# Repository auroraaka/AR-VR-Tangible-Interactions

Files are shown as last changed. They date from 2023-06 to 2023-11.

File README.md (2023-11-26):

# AR-VR-Tangible-Interactions
Created infrared (IR) camera and light attachments for Microsoft Hololens 1 and Oculus Quest 2. SolidWorks and STEP files are provided for CAD models (Hardware>IR_Camera_Apparatus>Microsoft_Hololens_1/Oculus_Quest_2). KiCad files are provided for the PCB and schematic of a compact IR light circuit (Hardware>IR_Camera_Apparatus>IR_Light). 

Programmed computer vision algorithms in Python to detect AruCo codes inside a custom-designed Ping Pong Paddle and Lightsaber. STL files are provided for the empty models and AruCo codes (Hardware>Ping_Pong_Paddle/Lightsaber). 

Mapped object movements to play:
- [Konterball](https://konterball.com/) in a web XR environment using 2D-to-3D conversion system assisted by PyAutoGUI (Software>Konterball).
- [Fruit Ninja](https://github.com/zigurous/unity-fruit-ninja-tutorial) in a wired PC-VR environment using C# scripts in Unity (Sofware>Fruit_Ninja). 

# Quick Links
__**ACM UIST Citation:**__  
Mustafa Doga Dogan, Raul Garcia-Martin, Patrick William Haertel, Jamison John O'Keefe, Ahmad Taka, Akarsh Aurora, Raul Sanchez-Reillo, and Stefanie Mueller. 2023. BrightMarker: 3D Printed Fluorescent Markers for Object Tracking. In Proceedings of the 36th Annual ACM Symposium on User Interface Software and Technology (UIST '23). Association for Computing Machinery, New York, NY, USA, Article 55, 1–13. https://doi.org/10.1145/3586183.3606758

__**Demo Video:**__    
Unlocking the Secret of BrightMarker: 3D Printed Fluorescent Markers for Object Tracking (https://www.youtube.com/watch?v=M5YNR6cVIiM)

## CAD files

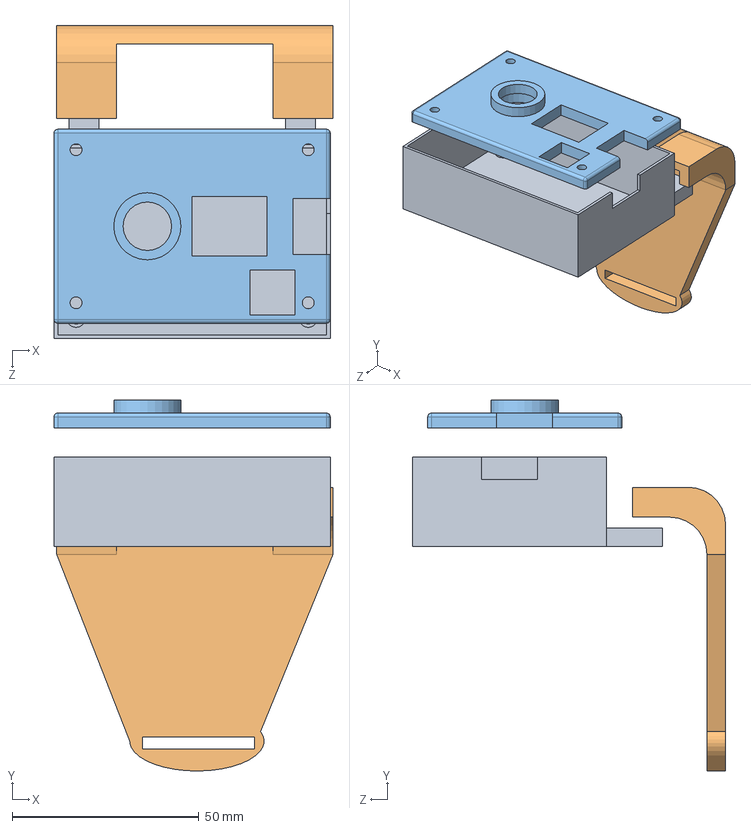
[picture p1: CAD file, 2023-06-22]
Hardware/IR_Camera_Apparatus/Oculus_Quest_2/SolidWorks/Oculus Quest 2 Assembly.SLDASM
74.7 x 99.4 x 83.9 mm
Oculus Quest 2 Bottom
Oculus Quest 2 Strap Plate
Oculus Quest 2 Top

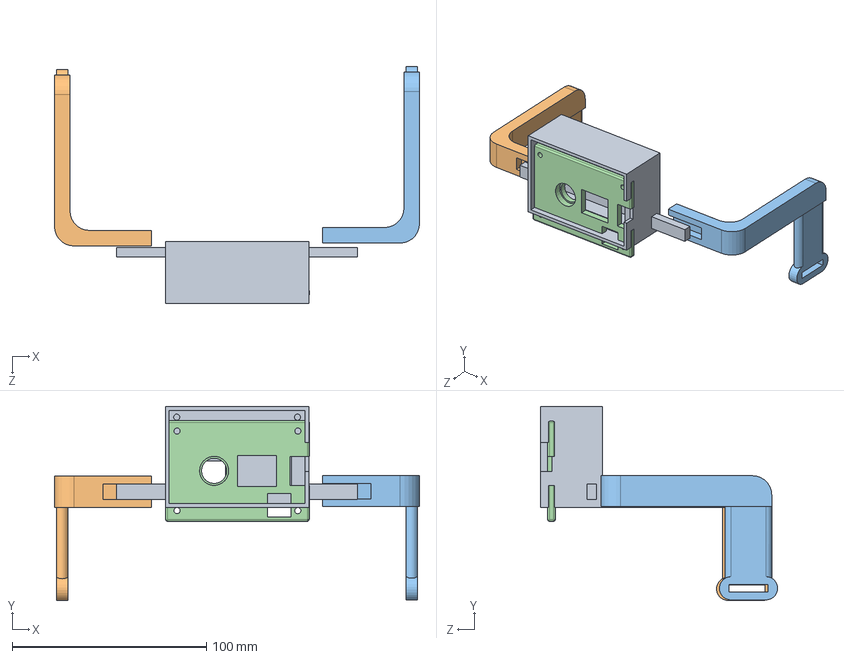
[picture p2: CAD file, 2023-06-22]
Hardware/IR_Camera_Apparatus/Microsoft_Hololens_1/SolidWorks/Hololens 1 Assembly.SLDASM
188.0 x 99.9 x 122.1 mm
Hololens 1 Bottom
Hololens 1 Left Arm
Hololens 1 Right Arm
Oculus Quest 2 Top

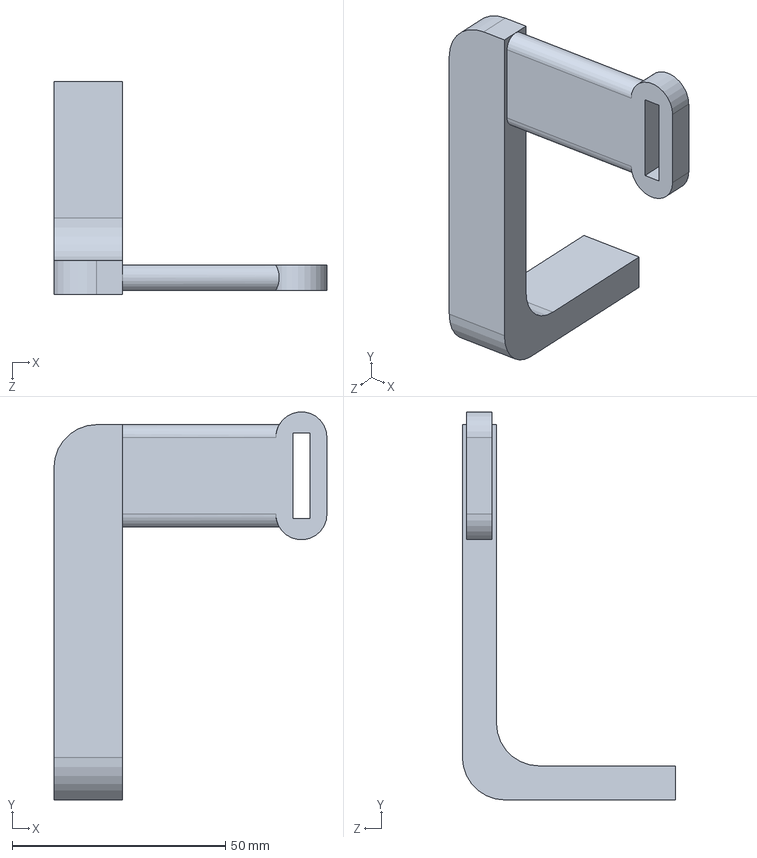
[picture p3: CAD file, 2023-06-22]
Hardware/IR_Camera_Apparatus/Microsoft_Hololens_1/SolidWorks/Hololens 1 Right Arm.SLDPRT
64.0 x 91.0 x 50.0 mm

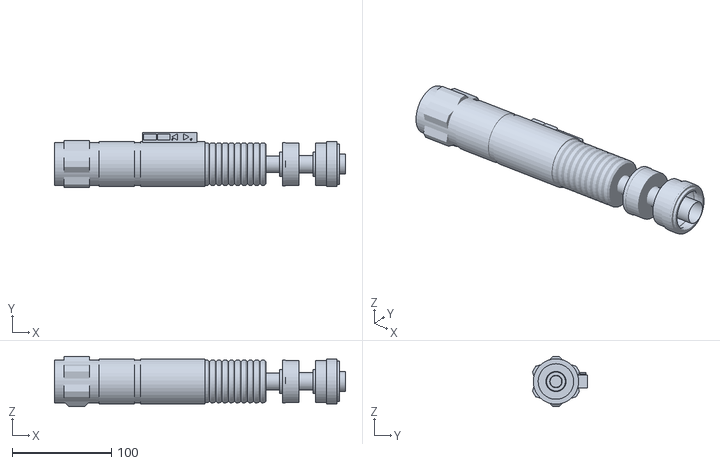
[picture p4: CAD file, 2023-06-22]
Hardware/Lightsaber/Lightsaber.STL
293.3 x 55.3 x 50.8

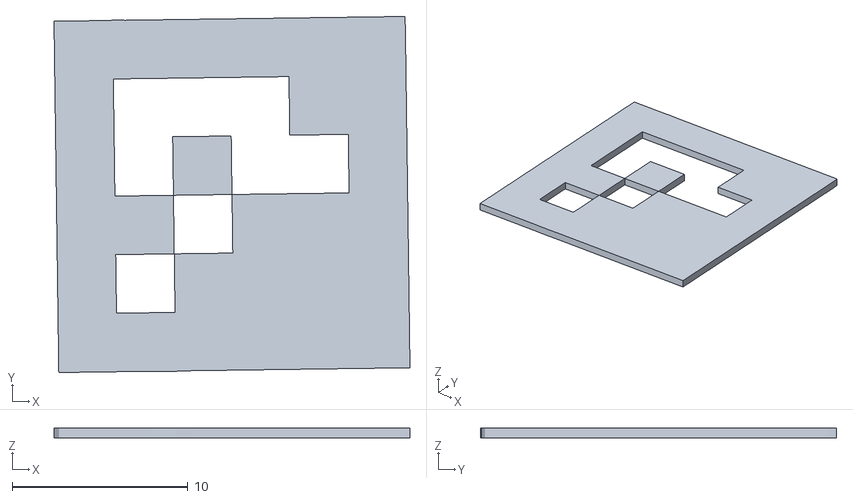
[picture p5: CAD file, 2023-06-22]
Hardware/Ping_Pong_Paddle/Ping_Pong_Paddle_AruCo.stl
20.3 x 20.3 x 0.58

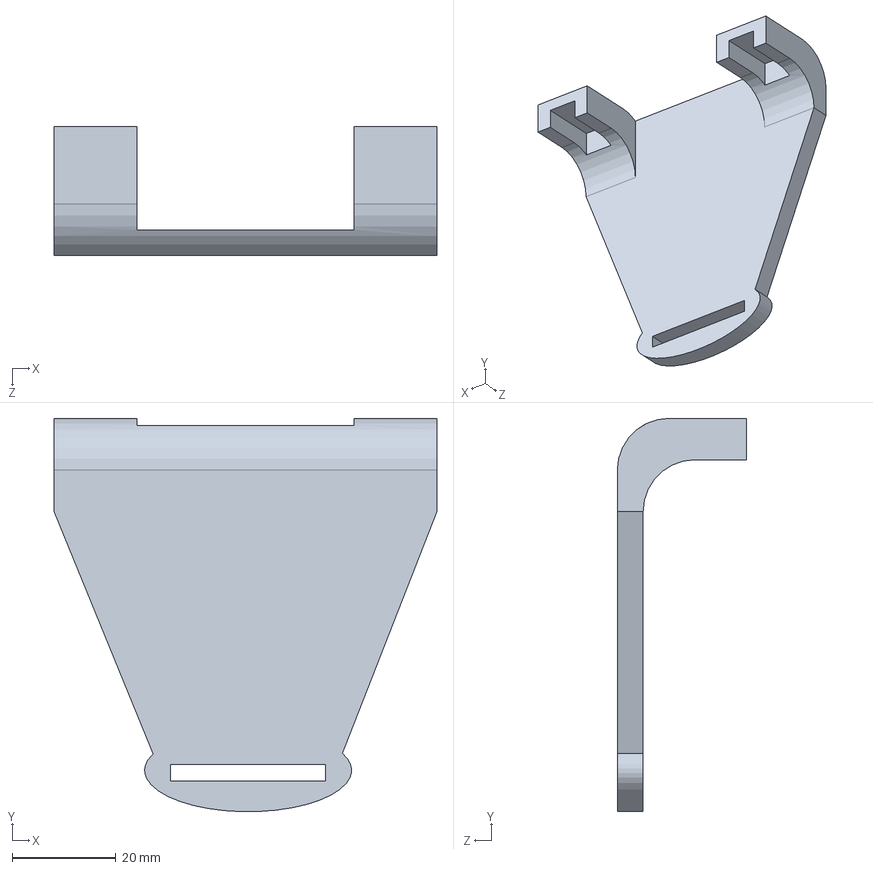
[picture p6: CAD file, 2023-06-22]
Hardware/IR_Camera_Apparatus/Oculus_Quest_2/SolidWorks/Oculus Quest 2 Strap Plate.SLDPRT
74.0 x 76.0 x 25.0 mm

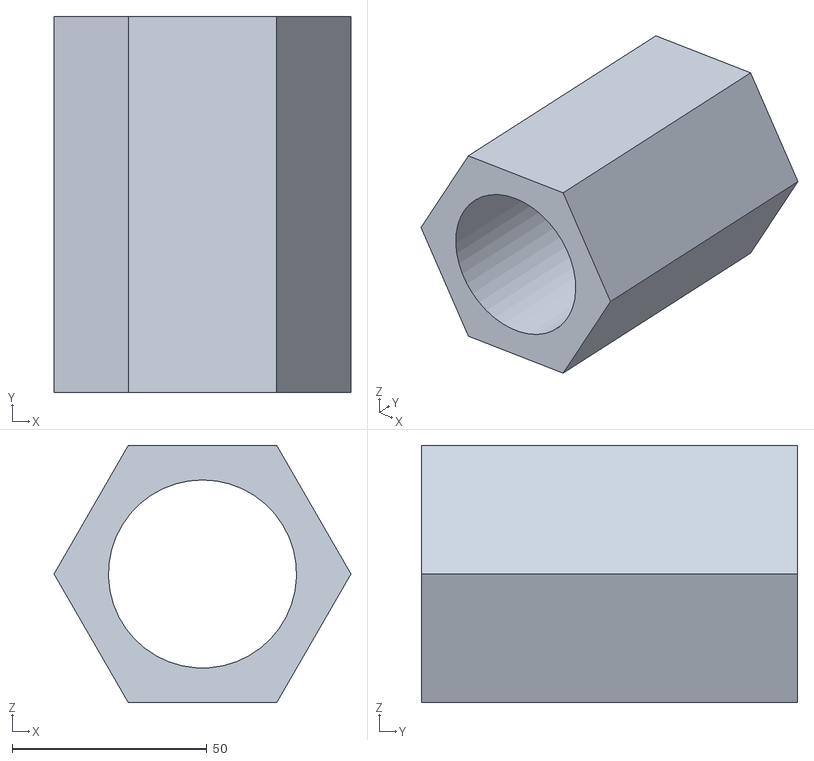
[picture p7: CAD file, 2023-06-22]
Hardware/Lightsaber/Lightsaber_Empty.stl
76.2 x 96.5 x 66.0

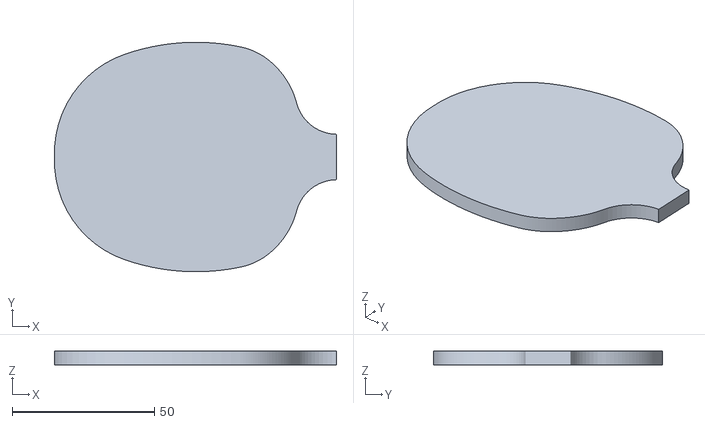
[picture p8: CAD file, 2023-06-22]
Hardware/Ping_Pong_Paddle/Ping_Pong_Paddle_Empty.stl
99.2 x 80.7 x 5.00

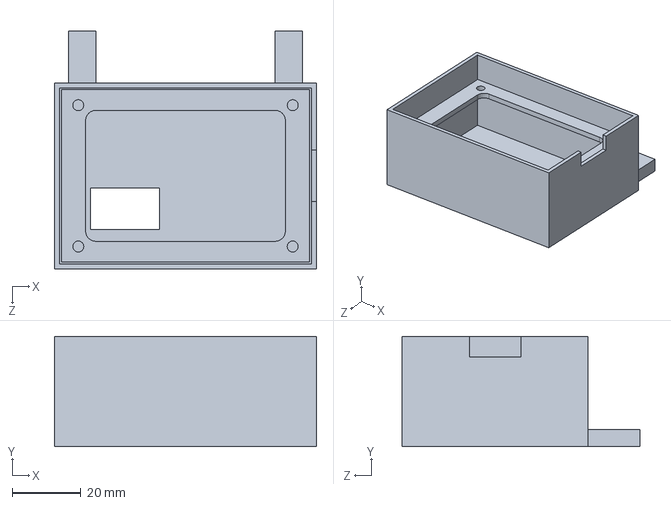
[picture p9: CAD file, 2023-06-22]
Hardware/IR_Camera_Apparatus/Oculus_Quest_2/SolidWorks/Oculus Quest 2 Bottom.SLDPRT
76.0 x 32.0 x 69.0 mm

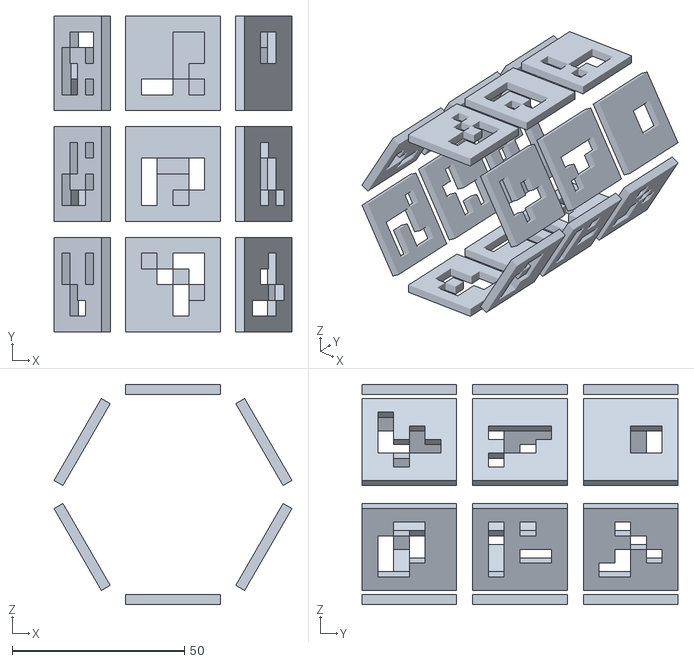
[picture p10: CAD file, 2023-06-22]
Hardware/Lightsaber/Lightsaber_AruCo.stl
69.2 x 91.8 x 64.0

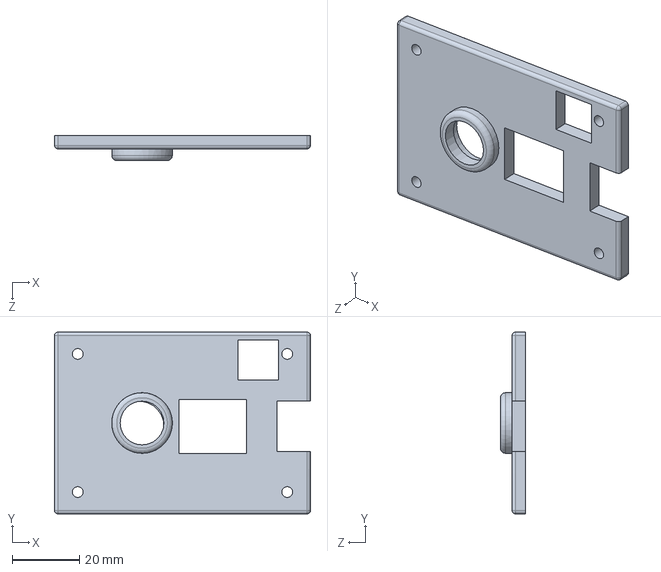
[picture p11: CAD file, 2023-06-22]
Hardware/IR_Camera_Apparatus/Microsoft_Hololens_1/SolidWorks/Hololens 1 Top.SLDPRT
76.0 x 54.0 x 7.50 mm

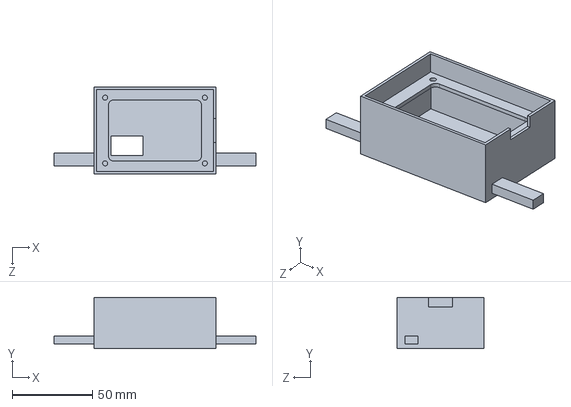
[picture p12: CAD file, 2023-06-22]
Hardware/IR_Camera_Apparatus/Microsoft_Hololens_1/SolidWorks/Hololens 1 Bottom.SLDPRT
126.0 x 32.0 x 54.0 mm

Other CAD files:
Hardware/IR_Camera_Apparatus/Microsoft_Hololens_1/SolidWorks/Hololens 1 Left Arm.SLDPRT
Hardware/IR_Camera_Apparatus/Microsoft_Hololens_1/STL/Hololens 1 Bottom.STL
Hardware/IR_Camera_Apparatus/Microsoft_Hololens_1/STL/Hololens 1 Left Arm.STL
Hardware/IR_Camera_Apparatus/Microsoft_Hololens_1/STL/Hololens 1 Right Arm.STL
Hardware/IR_Camera_Apparatus/Microsoft_Hololens_1/STL/Hololens 1 Top.STL
Hardware/IR_Camera_Apparatus/Oculus_Quest_2/STL/Oculus Quest 2 Bottom.STL
Hardware/IR_Camera_Apparatus/Oculus_Quest_2/STL/Oculus Quest 2 Strap Plate.STL
Hardware/IR_Camera_Apparatus/Oculus_Quest_2/STL/Oculus Quest 2 Top.STL

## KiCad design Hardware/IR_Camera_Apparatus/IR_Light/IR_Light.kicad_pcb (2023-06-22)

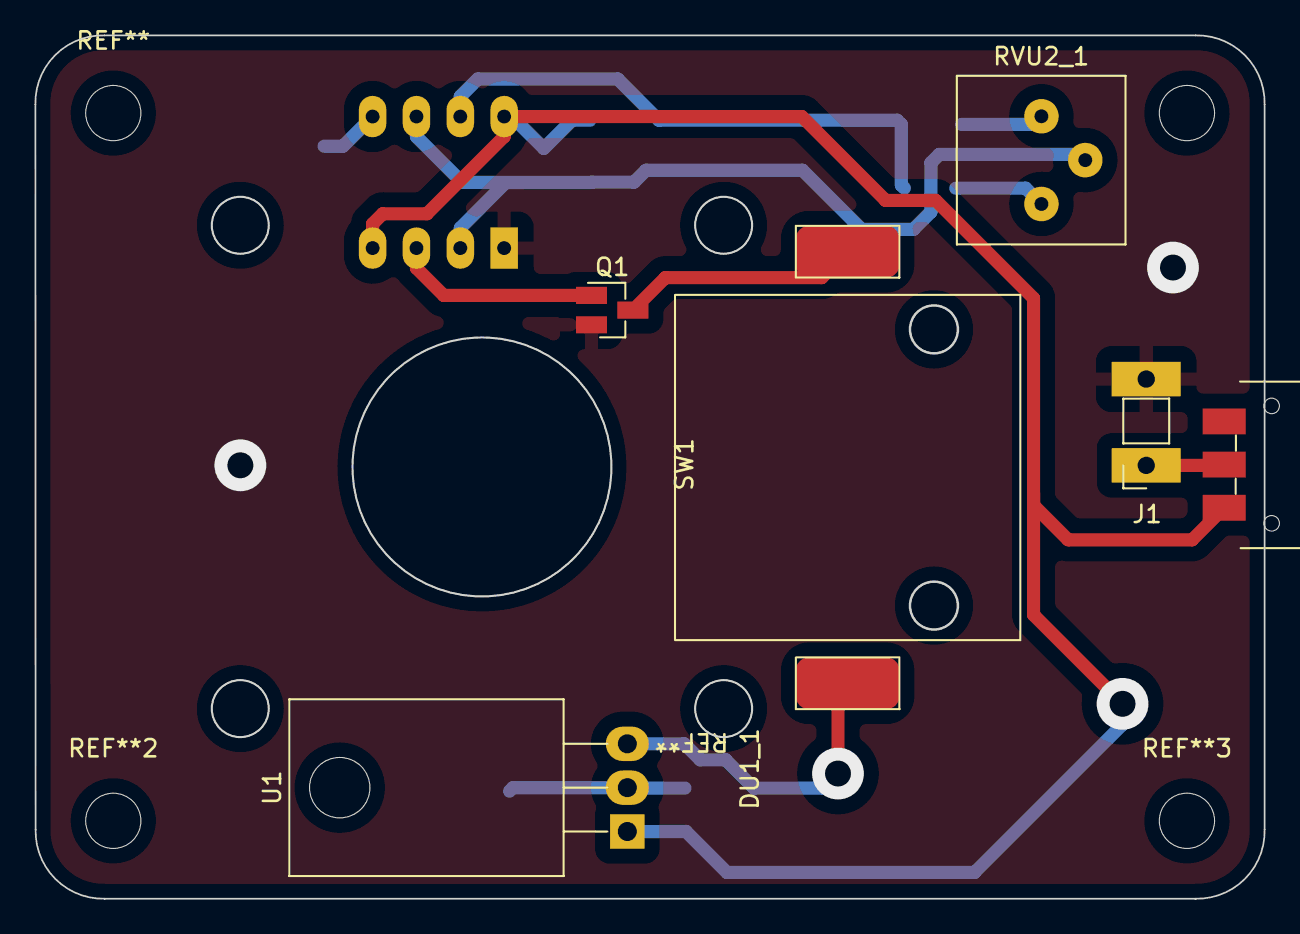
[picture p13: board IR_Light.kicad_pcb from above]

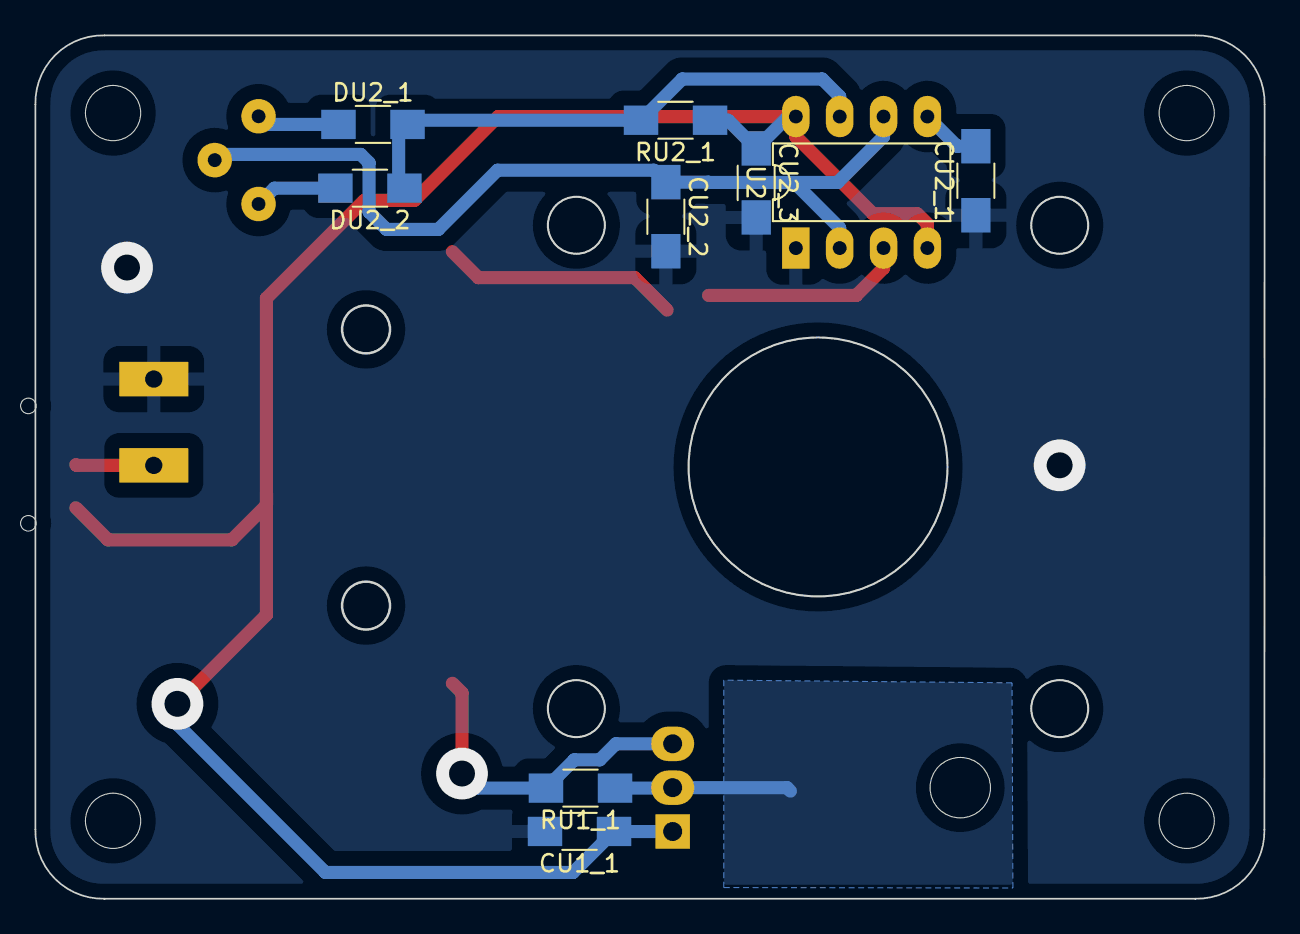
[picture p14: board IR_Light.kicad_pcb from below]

Board: 2 copper layers, 71.2 x 50.0 mm, 15 parts (9 on the bottom side), 12 nets.

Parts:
CU1_1, CU2_3: 10uF; C_1206
CU2_1, CU2_2: 10nF; C_1206
DU1_1: LED; IR_LED
DU2_1, DU2_2: 1N4148; R_1206
J1: Power; PinSocket_1x02_P2.54mm_Vertical
Q1: MOSFET_N-CH_30V_1.7A; SOT-23
RU1_1: 12.5; R_1206
RU2_1: 1K; R_1206
RVU2_1: 10K; Potentiometer_Bourns_3386P_Vertical
SW1: Pwr; Switch_SPDT_CnK_JS102011JCQN_9x3.6mm_P2.5mm
U1: LM317L_SO8; TO-220-3_Horizontal_TabDown
U2: LM555xM; DIP-8_W7.62mm_LongPads

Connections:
+9V: CU1_1.1, CU2_3.1, RU2_1.1, SW1.1 (A), U1.1 (VI), U2.4 (R), U2.8 (VCC)
/CTRL: Q1.1 (G), U2.3 (Q)
GND: CU1_1.2, CU2_1.1, CU2_2.2, CU2_3.2, J1.2, Q1.2 (S), U2.1 (GND)
unnamed: CU2_1.2, U2.5 (CV)
unnamed: CU2_2.1, RVU2_1.2, U2.2 (TR), U2.6 (THR)
unnamed: DU1_1.1 (K), Q1.3 (D)
unnamed: DU1_1.2 (A), RU1_1.2, U1.3 (ADJ)
unnamed: DU2_1.1 (K), RVU2_1.3
unnamed: DU2_1.2 (A), DU2_2.1 (K), RU2_1.2, U2.7 (DIS)
unnamed: DU2_2.2 (A), RVU2_1.1
unnamed: J1.1, SW1.2 (B)
unnamed: RU1_1.1, U1.2 (VO)
